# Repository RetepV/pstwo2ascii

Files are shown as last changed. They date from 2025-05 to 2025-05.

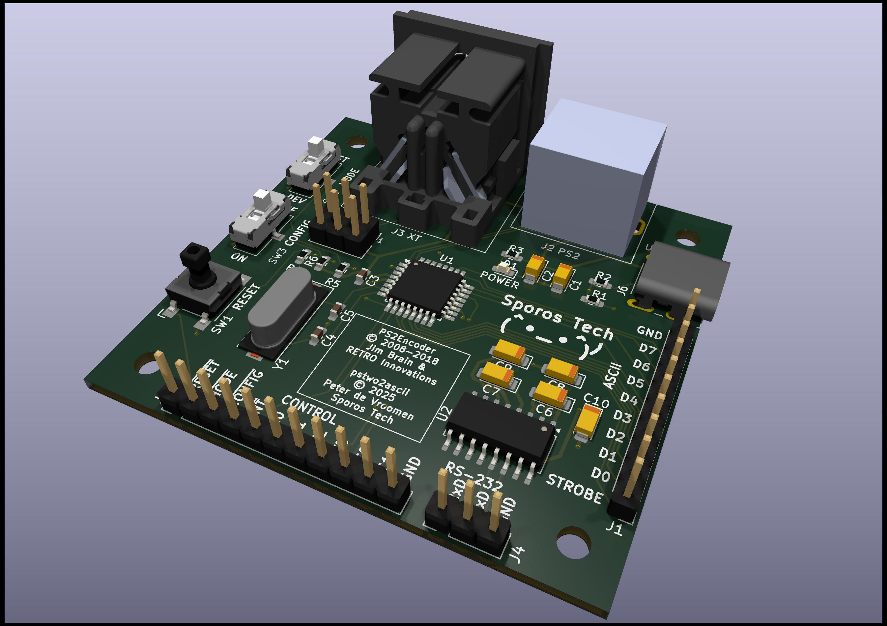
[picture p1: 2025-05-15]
Pretty/pstwo2ascii-3d.jpg

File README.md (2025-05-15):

# pstwo2ascii
My rendition of Jim Brain/RETRO Innovations **PS2Encoder**.

The original (copyrighted by Jim Brain and RETRO Innovations) can be found here: https://github.com/go4retro/PS2Encoder.

I decided to make the board USB powered, and add a "real" RS-232 V24 interface. Most vintage computers cannot work with 0V/5V, but need positive and negative voltages. And some old vintage computers output +12V and -12V, and wil very likely blow up the ATMEGA's ports. Lastly, I used an ATMEGA328 instead of an ATMEGA88, just because I have a few of those lying around.

I decided to make it in SMD, to keep the boards small. I took hand-solderability into account as much as possible. Of course the connectors mostly dictate the final size of the board, and t.b.h. I think that if I had used PTH components, the board would not be much larger. But there you go: it's my design and I can do what I want to. ;)

**Note: this is a WIP and has not been tested yet, prototypes have not even been created yet.**

The base design and the software is not mine, but created and copyrighted (2008-2018) by Jim Brain / RETRO Innovations. I took the base design, redesigned it to make a full-fledged board powered by USB and having a real RS-232 V24 interface using a MAX232, and named it **pstwo2ascii**. This board is meant to be used with the firmware of **PS2Encoder**, which can be found here: https://github.com/go4retro/PS2Encoder/tree/master. Big thanks and kudos to Jim Brain for his work!

Please note that **pstwo2ascii** is covered under GPLv3, while **PS2Encoder** is covered under GPLv2. **pstwo2ascii** only applies to the hardware designs that you can find in this repository.

## Licenses

### PS2Encoder

Copyright Jim Brain and RETRO Innovations, 2008-2018

These files are free designs; you can redistribute them and/or modify them under the terms of the GNU General Public License, version 2 as published by the Free Software Foundation.

These files are distributed in the hope that they will be useful, but WITHOUT ANY WARRANTY; without even the implied warranty of MERCHANTABILITY or FITNESS FOR A PARTICULAR PURPOSE. See the GNU General Public License for more details.

You should have received a copy of the GNU General Public License along with these files; if not, write to the Free Software Foundation, Inc., 51 Franklin Street, Fifth Floor, Boston, MA 02110-1301 USA.

### pstwo2ascii

Copyright Sporos Tech, Peter de Vroomen, 2025

**pstwo2ascii** is free software: you can redistribute it and/or modify it under the terms of the GNU General Public License as published by the Free Software Foundation, either version 3 of the License, or (at your option) any later version.

**pstwo2ascii** is distributed in the hope that it will be useful, but WITHOUT ANY WARRANTY; without even the implied warranty of MERCHANTABILITY or FITNESS FOR A PARTICULAR PURPOSE. See the GNU General Public License for more details.

You should have received a copy of the GNU General Public License along with **pstwo2ascii**. If not, see <https://www.gnu.org/licenses/>.

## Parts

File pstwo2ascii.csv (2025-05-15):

Id | Designator | Footprint | Quantity | Designation | Supplier and ref
1 | C1 | CP_EIA-3216-18_Kemet-A_Pad1.58x1.35mm_HandSolder | 1 | 10u/10v
2 | C2 | CP_EIA-3216-18_Kemet-A_Pad1.58x1.35mm_HandSolder | 1 | 0.1u/10v
3 | C3 | C_0603_1608Metric_Pad1.08x0.95mm_HandSolder | 1 | 100n
4 | C4,C5 | C_0603_1608Metric_Pad1.08x0.95mm_HandSolder | 2 | 18pF
5 | C6,C7,C8,C9,C10 | CP_EIA-3216-12_Kemet-S_Pad1.58x1.35mm_HandSolder | 5 | 1uF/16V
6 | J1 | PinHeader_1x10_P2.54mm_Vertical | 1 | ASCII
7 | J2 | Connector_Mini-DIN_Female_6Pin_2rows | 1 | PS2
8 | J3 | DIN-5-180 | 1 | XT
9 | J4 | PinHeader_1x03_P2.54mm_Vertical | 1 | RS232 v24
10 | J5 | PinHeader_1x11_P2.54mm_Vertical | 1 | Control
11 | J6 | USB_C_Receptacle_Molex_213716-0001 | 1 | USB-C Power
12 | R1,R2 | R_0603_1608Metric_Pad0.98x0.95mm_HandSolder | 2 | 5.11K
13 | R3 | R_0603_1608Metric_Pad0.98x0.95mm_HandSolder | 1 | 1.8K
14 | R4,R5,R6 | R_0603_1608Metric_Pad0.98x0.95mm_HandSolder | 3 | 10K
15 | SW1 | SW_SPST_Omron_B3FS-100xP_4P | 1 | RESET
16 | SW2 | CL-SB-12B-0x SPDT switch | 1 | MODE
17 | SW3 | CL-SB-12B-0x SPDT switch | 1 | CONFIG
18 | U1 | TQFP-32_7x7mm_P0.8mm | 1 | ATmega328-AU
19 | Y1 | Crystal_SMD_HC49-SD | 1 | 8MHz
20 | J7 | PinHeader_2x03_P2.54mm_Vertical | 1 | SPI
21 | U2 | SOIC-16_4.55x10.3mm_P1.27mm | 1 | MAX232
22 | D1 | LED_0603_1608Metric_Pad1.05x0.95mm_HandSolder | 1 | LED

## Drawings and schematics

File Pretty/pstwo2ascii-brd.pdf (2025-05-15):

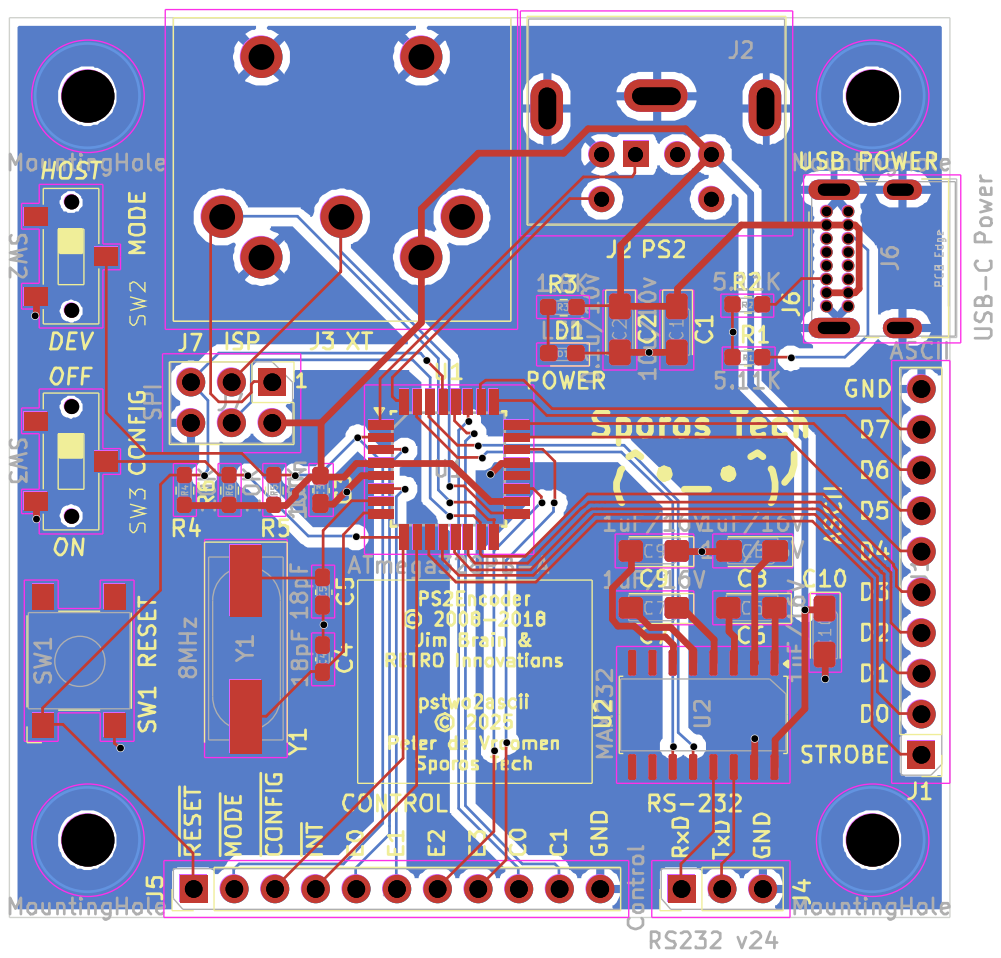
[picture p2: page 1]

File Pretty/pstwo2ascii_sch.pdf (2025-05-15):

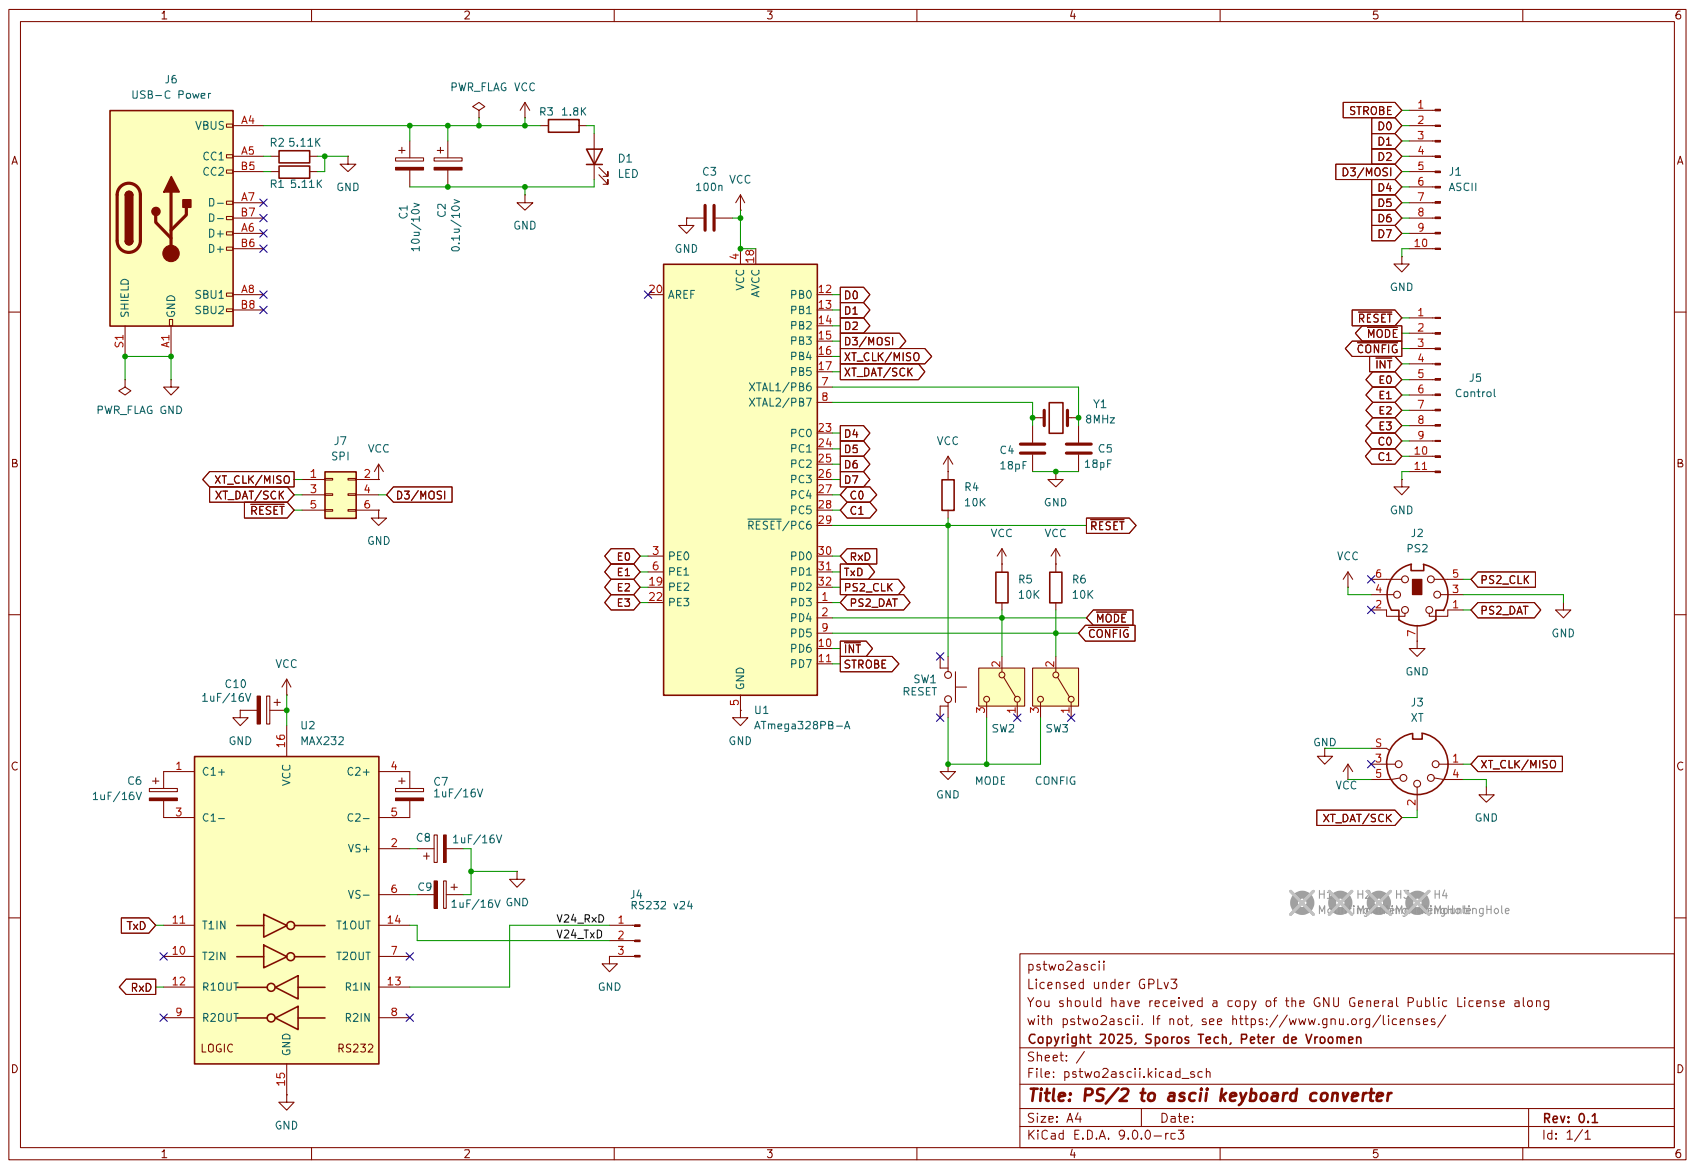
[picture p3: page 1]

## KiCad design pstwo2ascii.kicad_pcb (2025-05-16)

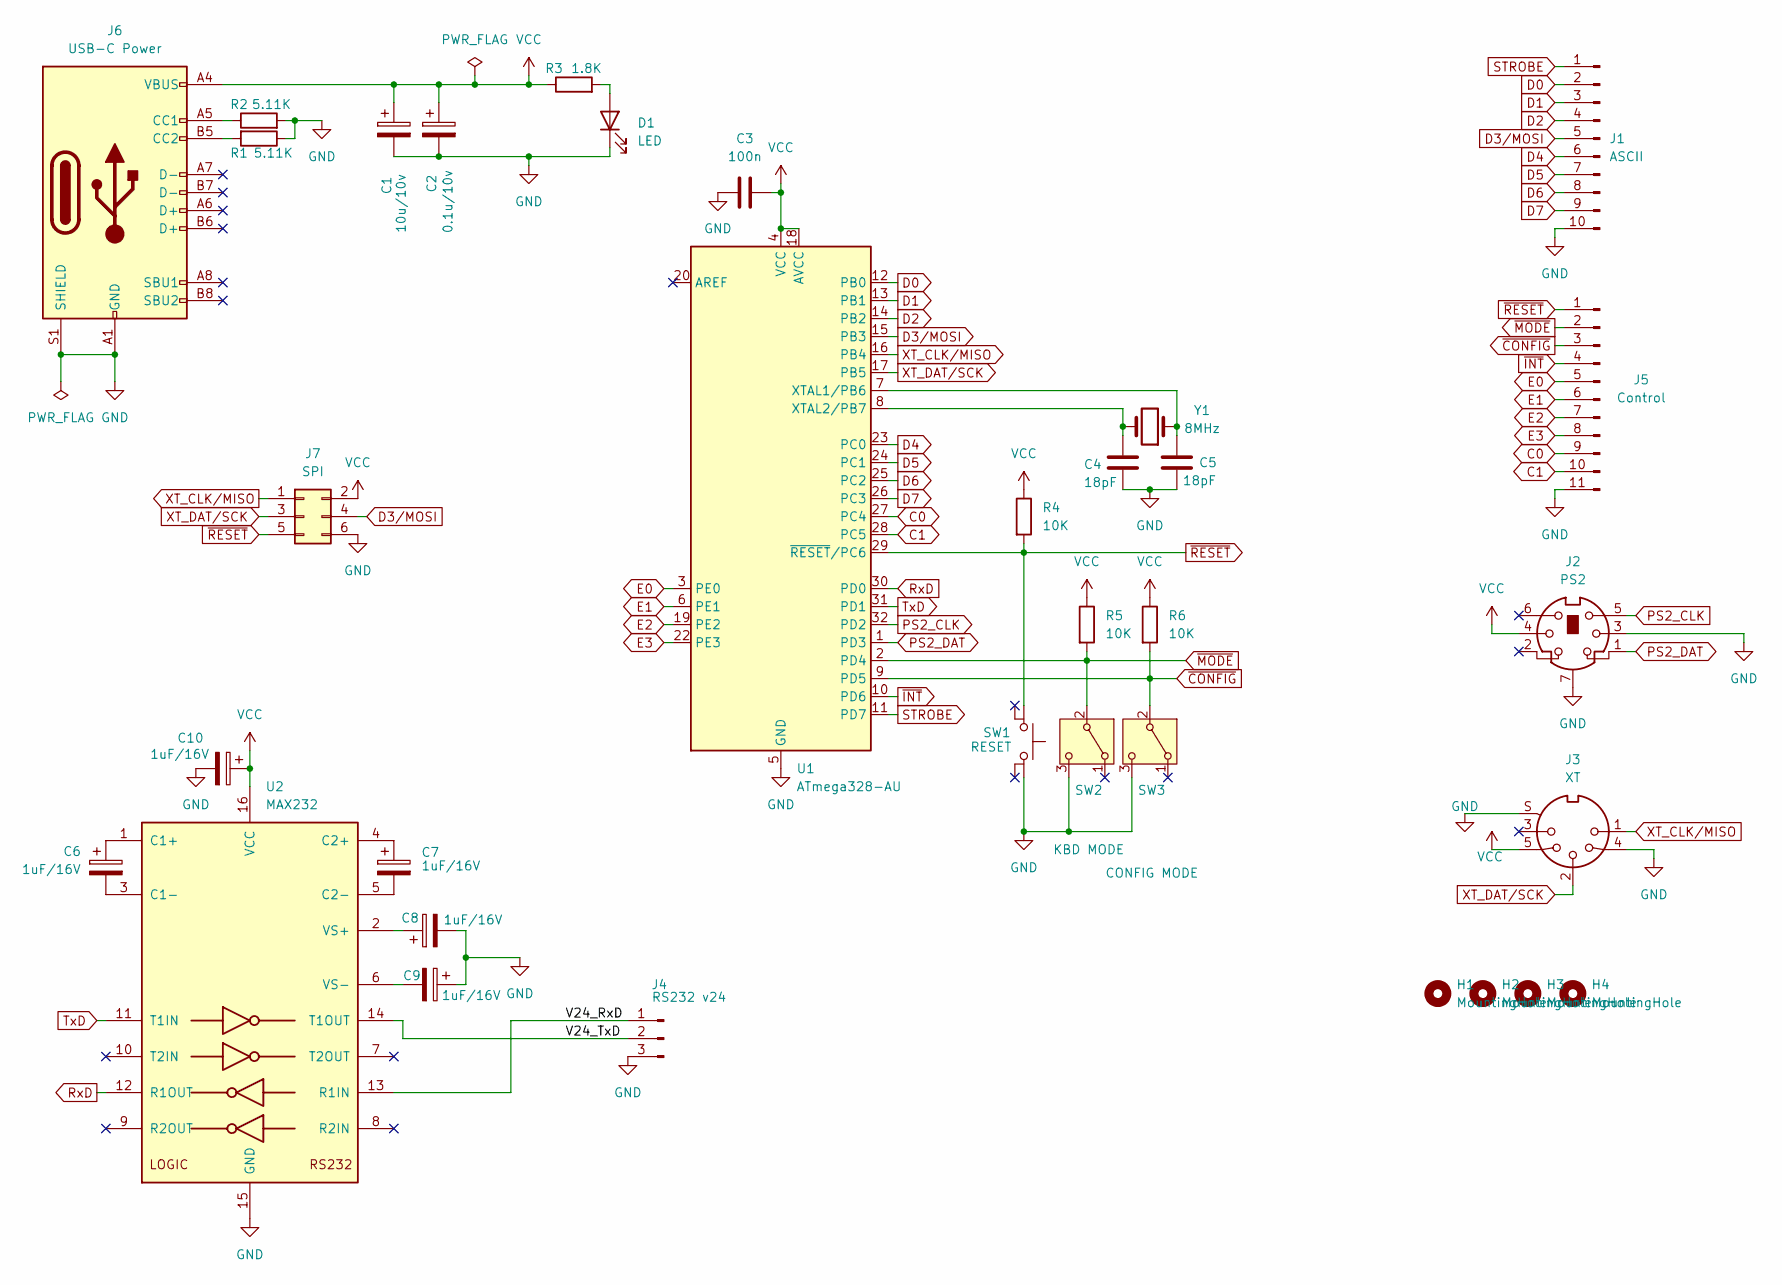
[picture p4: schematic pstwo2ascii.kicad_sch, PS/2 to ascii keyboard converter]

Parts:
C1: 10u/10v; CP_EIA-3216-18_Kemet-A_Pad1.58x1.35mm_HandSolder
C2: 0.1u/10v; CP_EIA-3216-18_Kemet-A_Pad1.58x1.35mm_HandSolder
C3: 100n; C_0603_1608Metric_Pad1.08x0.95mm_HandSolder
C4, C5: 18pF; C_0603_1608Metric_Pad1.08x0.95mm_HandSolder
C6, C7, C8, C9, C10: 1uF/16V; CP_EIA-3216-12_Kemet-S_Pad1.58x1.35mm_HandSolder
D1: LED; LED_0603_1608Metric_Pad1.05x0.95mm_HandSolder
H1, H2, H3, H4: MountingHole; MountingHole_3.2mm_M3
J1: ASCII; PinHeader_1x10_P2.54mm_Vertical
J2: PS2; Connector_Mini-DIN_Female_6Pin_2rows
J3: XT; DIN-5-180
J4: RS232 v24; PinHeader_1x03_P2.54mm_Vertical
J5: Control; PinHeader_1x11_P2.54mm_Vertical
J6: USB-C Power; USB_C_Receptacle_Molex_213716-0001
J7: SPI; PinHeader_2x03_P2.54mm_Vertical
R1, R2: 5.11K; R_0603_1608Metric_Pad0.98x0.95mm_HandSolder
R3: 1.8K; R_0603_1608Metric_Pad0.98x0.95mm_HandSolder
R4, R5, R6: 10K; R_0603_1608Metric_Pad0.98x0.95mm_HandSolder
SW1: RESET; SW_SPST_Omron_B3FS-100xP_4P
SW2: KBD MODE; CL-SB-12B-0x SPDT switch
SW3: CONFIG MODE; CL-SB-12B-0x SPDT switch
U1: ATmega328-AU; TQFP-32_7x7mm_P0.8mm
U2: MAX232; SOIC-16_4.55x10.3mm_P1.27mm
Y1: 8MHz; Crystal_SMD_HC49-SD

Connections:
/V24_RxD: J4.1, U2.13 (R1IN)
/V24_TxD: J4.2, U2.14 (T1OUT)
C0: J5.9, U1.27 (PC4)
C1: J5.10, U1.28 (PC5)
D0: J1.2, U1.12 (PB0)
D1: J1.3, U1.13 (PB1)
D2: J1.4, U1.14 (PB2)
D3/MOSI: J1.5, J7.4, U1.15 (PB3)
D4: J1.6, U1.23 (PC0)
D5: J1.7, U1.24 (PC1)
D6: J1.8, U1.25 (PC2)
D7: J1.9, U1.26 (PC3)
E0: J5.5, U1.3 (PE0)
E1: J5.6, U1.6 (PE1)
E2: J5.7, U1.19 (PE2)
E3: J5.8, U1.22 (PE3)
GND: C1.2, C2.2, C3.2, C4.2, C5.2, C8.2, C9.1, C10.2, D1.1 (K), J1.10, J2.3, J2.7, J3.4, J3.S, J4.3, J5.11, J6.A1 (GND), J6.A12 (GND), J6.B1 (GND), J6.B12 (GND), J6.S1 (SHIELD), J7.6, R1.1, R2.2, SW1.3, SW2.3 (C), SW3.3 (C), U1.5 (GND), U1.21 (GND), U2.15 (GND)
unnamed: D1.2 (A), R3.2
unnamed: J6.A5 (CC1), R2.1
unnamed: J6.B5 (CC2), R1.2
unnamed: C5.1, U1.7 (XTAL1/PB6), Y1.1
unnamed: C4.1, U1.8 (XTAL2/PB7), Y1.2
unnamed: C6.1, U2.1 (C1+)
unnamed: C6.2, U2.3 (C1-)
unnamed: C7.1, U2.4 (C2+)
unnamed: C7.2, U2.5 (C2-)
unnamed: C8.1, U2.2 (VS+)
unnamed: C9.2, U2.6 (VS-)
PS2_CLK: J2.5, U1.32 (PD2)
PS2_DAT: J2.1, U1.1 (PD3)
RxD: U1.30 (PD0), U2.12 (R1OUT)
STROBE: J1.1, U1.11 (PD7)
TxD: U1.31 (PD1), U2.11 (T1IN)
VCC: C1.1, C2.1, C3.1, C10.1, J2.4, J3.5, J6.A4 (VBUS), J6.A9 (VBUS), J6.B4 (VBUS), J6.B9 (VBUS), J7.2, R3.1, R4.1, R5.1, R6.1, U1.4 (VCC), U1.18 (AVCC), U2.16 (VCC)
XT_CLK/MISO: J3.1, J7.1, U1.16 (PB4)
XT_DAT/SCK: J3.2, J7.3, U1.17 (PB5)
~CONFIG: J5.3, R6.2, SW3.2 (B), U1.9 (PD5)
~INT: J5.4, U1.10 (PD6)
~MODE: J5.2, R5.2, SW2.2 (B), U1.2 (PD4)
~RESET: J5.1, J7.5, R4.2, SW1.1, U1.29 (~RESET/PC6)

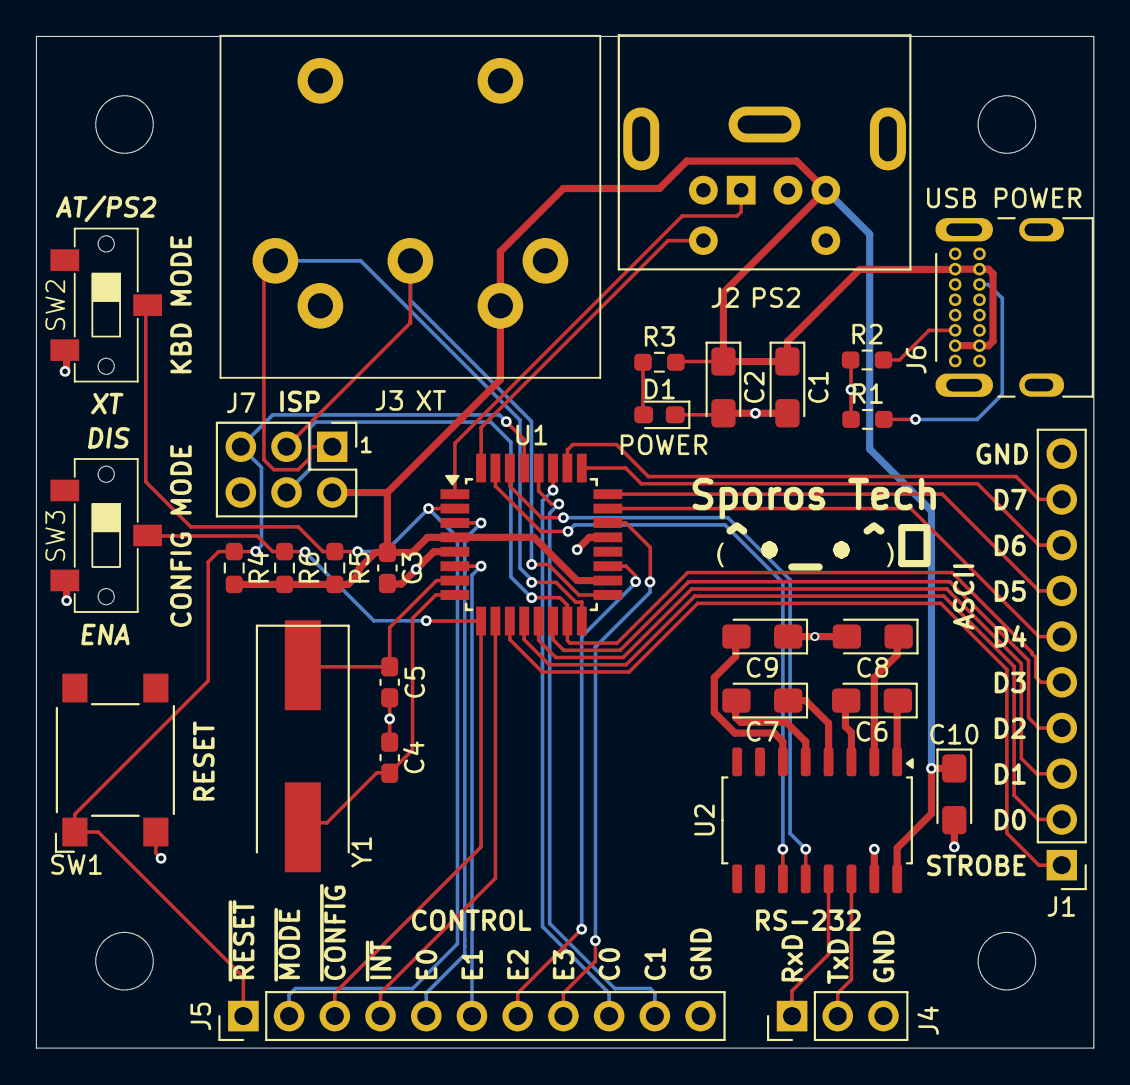
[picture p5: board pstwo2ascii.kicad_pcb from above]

Board: 2 copper layers, 58.7 x 56.2 mm, 34 parts (0 on the bottom side), 40 nets.

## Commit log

2025-05-14 Initial commit of pstwo2ascii PCB
    [pstwo2ascii.kicad_pcb, pstwo2ascii.kicad_sch]
2025-05-14 Improvements. Added 3D models, changed pushbuttons to slider switches. Clearer text.
    [pstwo2ascii.kicad_pcb, pstwo2ascii.kicad_sch]
2025-05-15 Added GPLv3 license file. Also some new backup created by Kicad.
2025-05-15 Add a few extra GND pins on the pin connectors. Also added copyright information in the sheets. Also updated pretty files.
    [pstwo2ascii.kicad_pcb, pstwo2ascii.kicad_sch]
2025-05-15 Some small improvements, and assigning datasheets.
    [pstwo2ascii.csv, pstwo2ascii.kicad_pcb, pstwo2ascii.kicad_sch]
2025-05-16 Some final tweaks, changing the labels of the buttons and switches.
    [pstwo2ascii.kicad_pcb, pstwo2ascii.kicad_sch]

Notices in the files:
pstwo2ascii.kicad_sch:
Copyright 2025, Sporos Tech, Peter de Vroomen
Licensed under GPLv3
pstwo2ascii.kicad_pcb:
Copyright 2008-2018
